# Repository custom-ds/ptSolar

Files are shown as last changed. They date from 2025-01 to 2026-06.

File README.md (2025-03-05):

# ptSolar
The ptSolar is the newest version of Project: Traveler's series of APRS trackers. The ptSolar has been designed and optimized for low-power operation, especially when using a solar panel.

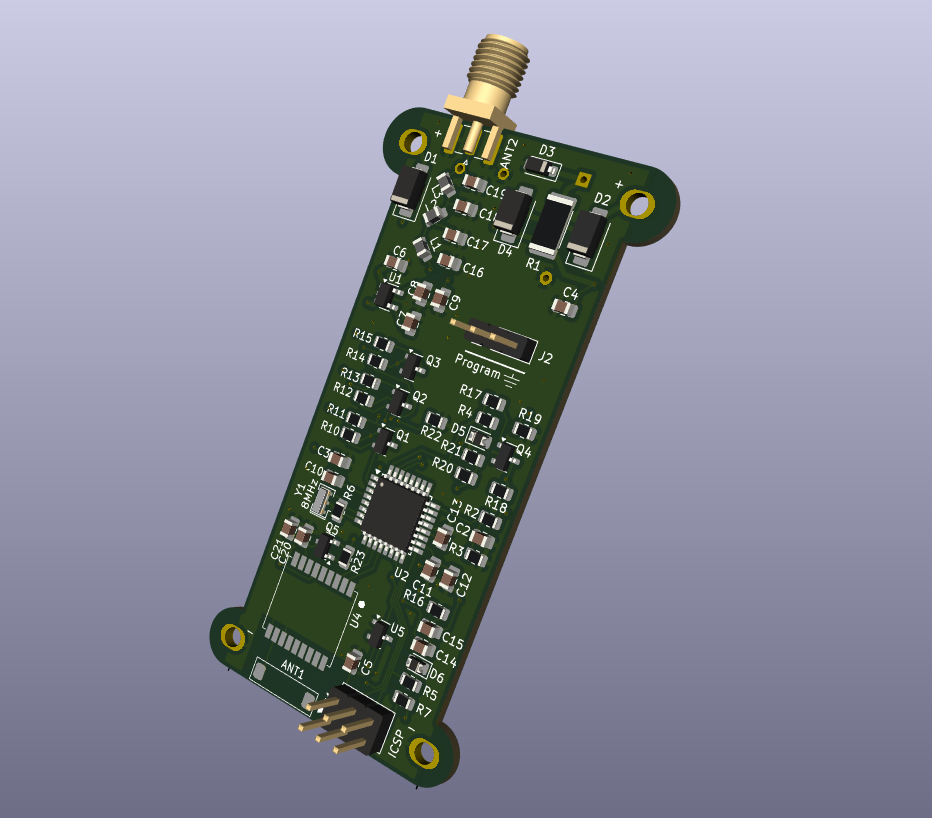
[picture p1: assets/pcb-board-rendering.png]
3D rendering of the ptSolar circuit board.


Under the hood, the ptSolar runs on the same __Microchip ATMega328p__ microcontroller that the other trackers have been using for years, although this board runs at a lower 3.3 volt level, and a slower 8MHz clock speed.

A 2m VHF transmitter is provided by the __SA818S-V__ transmitter-on-a-chip system, which means it's frequency agile and can be used throughout the world.

The GPS receiver is utilizes the __ATGM336H__ GPS engine which has a light-weight footprint while being a cost-effective solution. The ATGM336H is capable of position reports in excess of 60,000', making it a suitable solution for high altitude (latex) balloons traveling to over 100,000'.

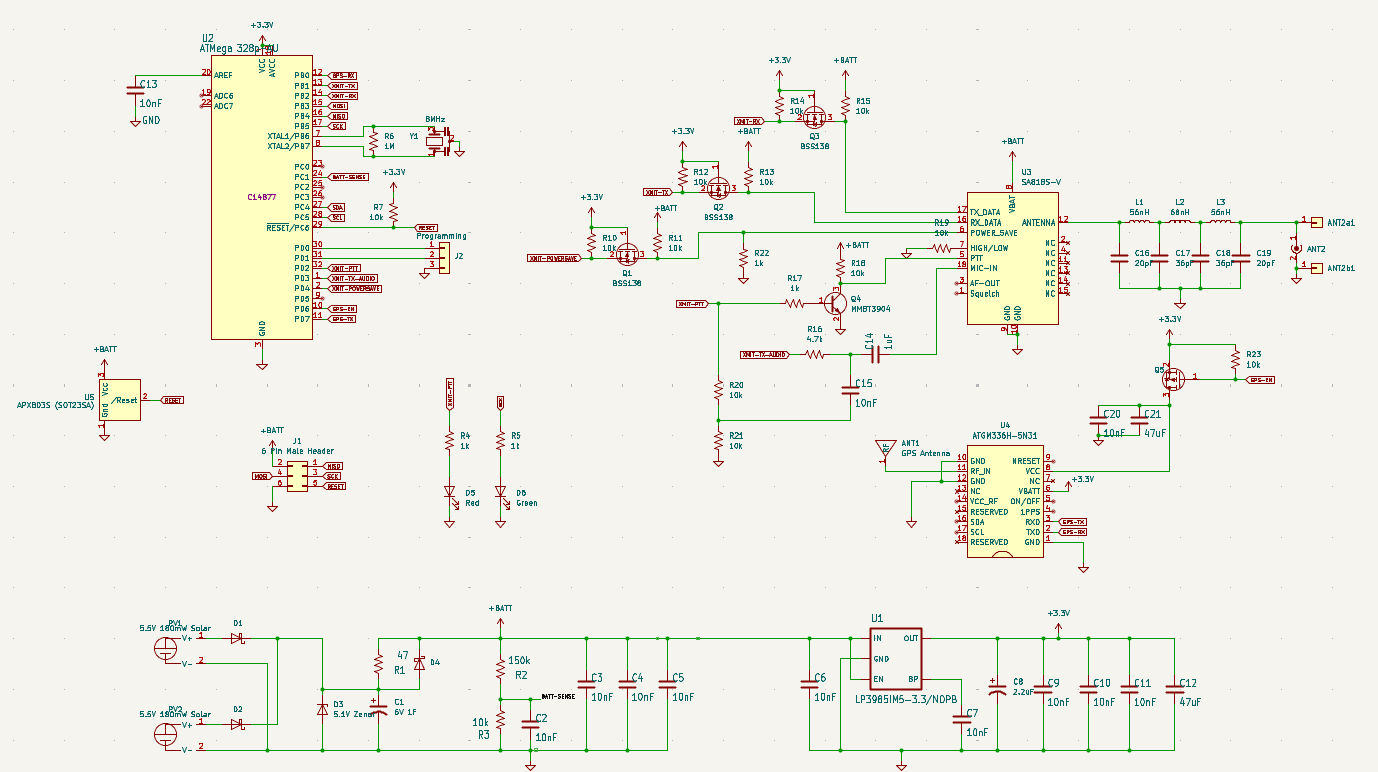
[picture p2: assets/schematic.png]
ptSolar schematic diagram.


## The Circuit Board
The circuit board is designed in Kicad and features a 4-layer design with castellated solder points for the attached solar panels.

The ptSolar is currently in the prototyping stages. Version 1.1.0 of the PCB was the initial design that was first built in early 2025, and includes the ATMega328p microcontroller, an ATGM336H GPS receiver, and the SA818S-V VHF transmitter. VHF signal filtering is provided by a 3-pole pi filter, reducing spurious harmonic output to well within Part 97 specifications.

## The Breakout Board
A Breakout board has been developed that can be temporarily or permanently paired to the top of the ptSolar tracker. The breakout includes a second ISCP programming port, a second serial data interface for configuring the tracker, a Sparkfun Qwiic connector for interfacing with other I2C sensors.

There is also a 2.1mm barrel jack for accepting power from a battery pack, along with the required 5V regulator when operating at higher supplied voltages. 

The Breakout Board mates to the tracker with a female .1" header connecting into the 6-pin (ISCP) and 8-pin (Serial, I2C) plugs on the ptSolar.

## Preparing the IDE for the Firmware
In the Arduino IDE and go to File &rarr; Preferences.  In the Additional Boards Manager URLs field, add the URL to the Project: Traveler website .json file:

```
https://www.projecttraveler.org/downloads/package_projecttraveler_index.json
```

Note that if there's already something in that field, you can click the small icon to the right of the text field where you are allowed to enter multiple entries on multiple lines.

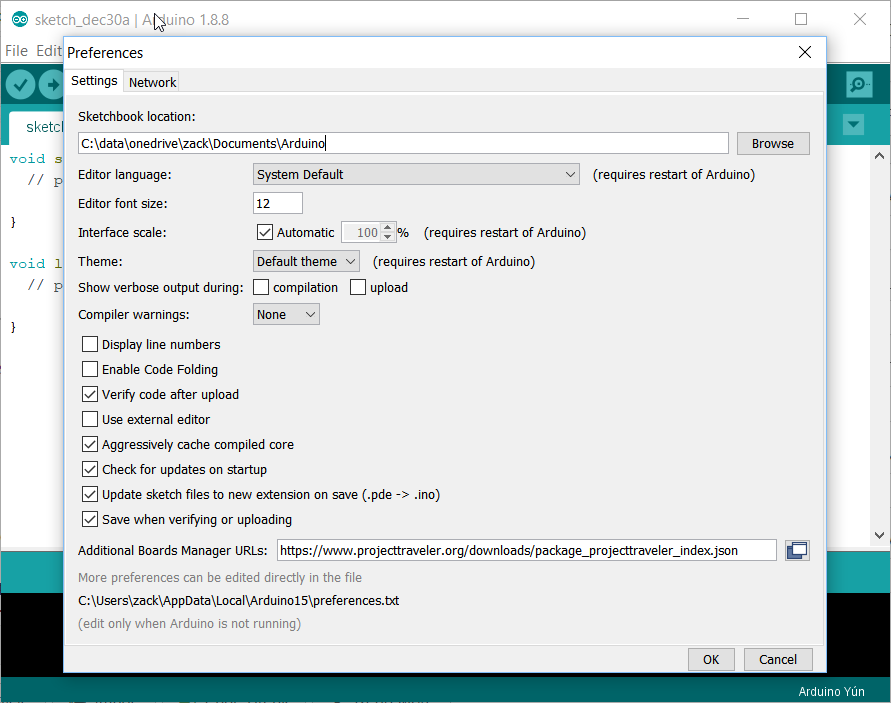
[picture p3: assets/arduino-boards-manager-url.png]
Setting the custom download URL for the Boards Manager.


Click OK to close the preferences dialog.  Then go to Tools &rarr; Boards &rarr; Boards Manager.

When the Boards Manager opens, select "Contributed" from the Type drop-down.  In the resulting list, you should find the Project Traveler Boards by Project Traveler option.  Click the Install button in the lower-right corner.

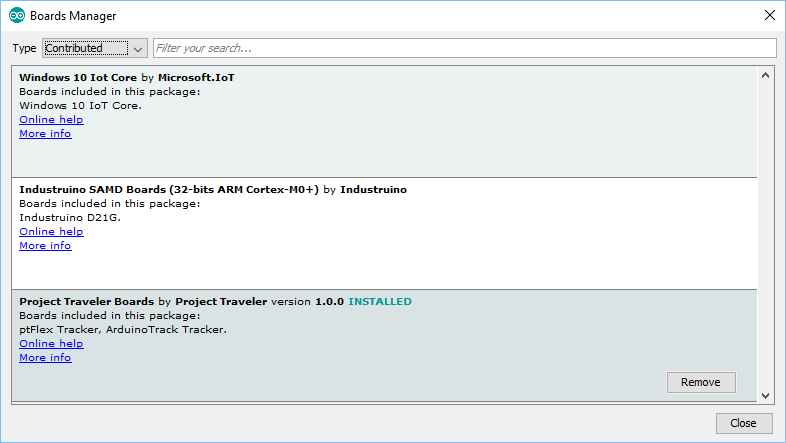
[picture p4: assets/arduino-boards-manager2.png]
Using the Boards Manager in Arduino IDE.


Close out of the Boards Manager dialog, and the back under Tools &rarr; Board, you should see "ptSolar Tracker (Arduino as ISP)" near the bottom of the list. 

## Setting the Controller Flags
If this is a brand new ptSolar board that has never been programmed before, there are several commands that must be run from a DOS command prompt. If the ptSolar was purchased as an assembled and tested kit, you can skip these steps.

The fuses are to be set as follows:
* Low: 0xFF
* High: 0xD6
* Extended: 0xFD

To program the fuses using the AVRDude tool (which is included in the Arduino IDE, and works with the Arduino As ISP programmer), open a command prompt on the PC.

```
C:\> cd \Program Files (x86)\Arduino\hardware\tools\avr\bin
C:\...> avrdude.exe -p m328p -b 19200 -c avrisp -C ..\etc\avrdude.conf -P comX* -U lfuse:w:0xDF:m -U hfuse:w:0xD6:m -U efuse:w:0xFD:m
```
Depending on your installation of the Arduino IDE, your avrdude may also be found in:

```
C:\Users\{Username}\AppData\Local\Arduino15\packages\arduino\tools\avrdude\6.3.0-arduino17\bin
```

This will write the fuses to the new processor.  To verify that the fuses have been written, run these commands:

```
avrdude.exe -p m328p -b 19200 -c avrisp -C ..\etc\avrdude.conf -P comX* -U lfuse:w:0xFF:m -U hfuse:w:0xD6:m -U efuse:w:0xFD:m 
```

\* Replace "comX" with whatever Com port your ArduinoISP is enumerating on.

### Verifying the Fuses
```
C:\...> avrdude.exe -p m328p -b 19200 -c avrisp -C ..\etc\avrdude.conf -P comX* -U lfuse:r:lowfuse:h -U hfuse:r:highfuse:h -U efuse:r:exfuse:h
C:\...> type lowfuse
C:\...> type highfuse
C:\...> type exfuse
```

\* Replace "comX" with whatever Com port your ArduinoISP is enumerating on.

## Loading the Firmware
To program the ptSolar, open the firmware Sketch in this GitHub Repository in the Arduino IDE. 

Go to the Tools &rarr; Board menu, select the "ptSolar Tracker (Arduino as ISP)" from the list of targets.  

The ptSolar boards are automatically configured to use the Arduino as ISP programmer to load the firmware onto the tracker boards, so no further configuration is necessary. Click the Upload button which will cause the Sketch to compile and will program to the ATmega328 processor similarly to how a normal Arduino board is programmed.

Sometimes it is necessary to apply external power to the ptSolar Tracker, depending on how much current the Programmer board is capable of sourcing.

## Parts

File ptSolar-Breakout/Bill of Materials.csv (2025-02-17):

Reference | Value | Datasheet | Footprint | Qty | DNP | Digikey
C1 | Piezo Buzzer | ~ | Capacitor_THT:CP_Radial_D12.5mm_P7.50mm | 1 |  | 102-1155-ND
C2,C4,C5,C6 | 10nF | ~ | Capacitor_SMD:C_0805_2012Metric | 4 |  | 399-1158-1-ND
C3 | 2.2uF | ~ | Capacitor_SMD:C_0805_2012Metric | 1 |  | 445-1420-1-ND
D1 | 1N4007FL |  | Diode_SMD:D_SOD-123 | 1 |  | 1655-1N4007FLCT-ND
J1 | 6 Pin Female Socket | ~ | Connector_PinHeader_2.54mm:PinHeader_2x03_P2.54mm_Vertical | 1 |  | 952-1781-ND
J2 | Qwiic | ~ | Connector_JST:JST_SH_SM04B-SRSS-TB_1x04-1MP_P1.00mm_Horizontal | 1 |  | 455-1804-1-ND
J3 | 6 Pin Male Header | ~ | Connector_PinHeader_2.54mm:PinHeader_2x03_P2.54mm_Vertical | 1 |  | 732-5394-ND
J4 | 8 Pin Female Socket | ~ | Connector_PinHeader_2.54mm:PinHeader_2x04_P2.54mm_Vertical | 1 |  | 952-1790-ND
J5 | 3 Pin Male Header | ~ | Connector_PinHeader_2.54mm:PinHeader_1x03_P2.54mm_Vertical | 1 |  | 732-5316-ND
J6 | Barrel_Jack_Switch | ~ | Connector_BarrelJack:BarrelJack_CLIFF_FC681465S_SMT_Horizontal | 1 |  | CP-002AHPJCT-ND
Q1 | MMBT3904 | https://www.onsemi.com/pdf/datasheet/pzt3904-d.pdf | Package_TO_SOT_SMD:SOT-23 | 1 |  | MMBT3904TPMSCT-ND
R1 | 1k | ~ | Resistor_SMD:R_0805_2012Metric | 1 |  | 311-1.0KARCT-ND
SW2 | Reset Switch | ~ | Button_Switch_SMD:SW_SPST_B3S-1000 | 1 |  | CKN9104CT-ND
U1 | LM1086-5.0 |  | Package_TO_SOT_SMD:TO-263-3_TabPin2 | 1 |  | LM1086ISX-5.0/NOPBCT-ND

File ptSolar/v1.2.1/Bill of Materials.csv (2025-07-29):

Reference | Value | Datasheet | Footprint | Qty | DNP | Digikey | LCSC
ANT1 | GPS Antenna |  | Custom DS:Pulse ANT8010LL05R1575A Antenna | 1 |  | 553-ANT8010LL05R1575ACT-ND | C3284202
ANT2 | SMA Edge Mount (Optional) | ~ | Connector_Coaxial:SMA_Samtec_SMA-J-P-H-ST-EM1_EdgeMount | 1 |  | CON-SMA-EDGE-S-ND
ANT2a1,ANT2b1 | VHF Test Point | ~ | Custom DS:Small Test Point Pin | 2
C1 | 6V 1F | ~ | Custom DS:CDS CSP Super Cap 8mm dia | 1 |  | 4688-CSP-6R0L105R-TW-ND
C2,C3,C4,C5,C6,C7,C9,C10,C11,C13,C15,C20 | 10nF | ~ | Capacitor_SMD:C_0805_2012Metric | 12 |  | 399-1158-1-ND | C83170
C8 | 2.2uF | ~ | Capacitor_SMD:C_0805_2012Metric | 1 |  | 445-1420-1-ND | C107128
C12,C21 | 47uF | ~ | Capacitor_SMD:C_0805_2012Metric | 2 |  | 399-C0805C476M9PACTUCT-ND | C16780
C14 | 1uF | ~ | Capacitor_SMD:C_0805_2012Metric | 1 |  | 311-1886-1-ND | C28323
C16,C19 | 20pF | ~ | Capacitor_SMD:C_0805_2012Metric | 2 |  | 712-1381-1-ND | C105173
C17,C18 | 36pF | ~ | Capacitor_SMD:C_0805_2012Metric | 2 |  | 478-10473-1-ND | C541518
D1,D2,D4 | CDBA340L-G Schottky | ~ | Diode_SMD:D_SMA | 3 |  | 641-1258-1-ND | C22364900
D3 | 5.1V Zenor | ~ | Diode_SMD:D_SOD-123 | 1 |  | MMSZ5231B-FDICT-ND | C85181
D5 | Red | ~ | Diode_SMD:D_0805_2012Metric | 1 |  | LTST-C171KRKT | C2295
D6 | Green | ~ | Diode_SMD:D_0805_2012Metric | 1 |  | LTST-C171GKT | C2297
J1 | 6 Pin Male Header | ~ | Connector_PinHeader_2.54mm:PinHeader_2x03_P2.54mm_Vertical | 1 |  | 732-5394-ND
J2 | Programming | ~ | Connector_PinHeader_2.54mm:PinHeader_1x03_P2.54mm_Vertical | 1 |  | 732-5316-ND
L1,L3 | 56nH | ~ | Inductor_SMD:L_0805_2012Metric | 2 |  | 535-11570-1-ND | C98996
L2 | 68nH | ~ | Inductor_SMD:L_0805_2012Metric | 1 |  | 535-11572-1-ND | C75652
PV1,PV2 | 5.5V 180mW Solar | https://www.powerfilmsolar.com/hubfs/documents/spec%20sheets/electronic%20component%20solar%20panels/electronic%20component%20solar%20panels%20spec%20sheet_cl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 | Custom DS:PowerFilm MPT3.6-75 | 2 |  | 1996-1020-ND
Q1,Q2,Q3 | BSS138 | https://www.onsemi.com/pub/Collateral/BSS138-D.PDF | Package_TO_SOT_SMD:SOT-23 | 3 |  | BSS138TR-ND | C40912
Q4 | MMBT3904 | https://www.onsemi.com/pdf/datasheet/pzt3904-d.pdf | Package_TO_SOT_SMD:SOT-23 | 1 |  | MMBT3904TPMSCT-ND | C81464
Q5 | DMP2004K-7 |  | Package_TO_SOT_SMD:SOT-23 | 1 |  | DMP2004KDICT-ND | C332297
R1 | 47 | ~ | Resistor_SMD:R_2512_6332Metric | 1 |  | YAG3404CT-ND | C513678
R2 | 150k | ~ | Resistor_SMD:R_0805_2012Metric | 1 |  | 311-150KCRCT-ND | C114558
R3,R7,R10,R11,R12,R13,R14,R15,R18,R19,R20,R21,R23 | 10k | ~ | Resistor_SMD:R_0805_2012Metric | 13 |  | 13-RT0805FRD0710KLCT-ND | C100047
R4,R5,R17,R22 | 1k | ~ | Resistor_SMD:R_0805_2012Metric | 4 |  | 311-1.0KARCT-ND | C95781
R6 | 1M | ~ | Resistor_SMD:R_0805_2012Metric | 1 |  | 311-1.0MARCT-ND | C107700
R16 | 4.7k | ~ | Resistor_SMD:R_0805_2012Metric | 1 |  | 311-4.7KARCT-ND | C60816
U1 | LP3985IM5-3.3/NOPB | https://www.ti.com/lit/ds/symlink/lp3985.pdf?HQS=dis-dk-null-digikeymode-dsf-pf-null-wwe&ts=1737860010554 | Package_TO_SOT_SMD:SOT-23-5 | 1 |  | LP3985IM5-3.3/NOPBCT-ND | C108877
U2 | ATMega 328p-AU | https://ww1.microchip.com/downloads/en/DeviceDoc/Atmel-7810-Automotive-Microcontrollers-ATmega328P_Datasheet.pdf | Package_QFP:TQFP-32_7x7mm_P0.8mm | 1 |  | ATMEGA328P-AU-ND | C14877
U3 | SA818S-V |  | Custom DS:DRA818 SA818 | 1 |  | ALIEXPRESS
U4 | ATGM336H-5N31 | https://www.tinytronics.nl/product_files/002176_ATGM336H.pdf | Custom DS:ATGM336H-5N31 | 1 |  | ALIEXPRESS | C90770
U5 | APX803S (SOT23SA) |  | Package_TO_SOT_SMD:SOT-23 | 1 |  | APX803S-31SA-7DICT-ND | C129757
Y1 | 8MHz | ~ | Crystal:Resonator_SMD_Murata_CSTxExxV-3Pin_3.0x1.1mm | 1 |  | 490-CSTNE8M00G520000R0CT-ND | C907975

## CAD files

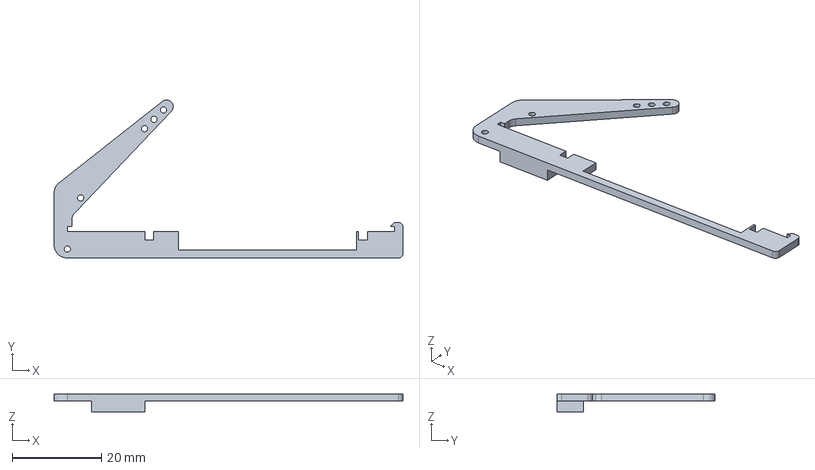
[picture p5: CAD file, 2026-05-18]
3d-prints/Angled Carrier.FCStd
78.4 x 35.5 x 4.00 mm

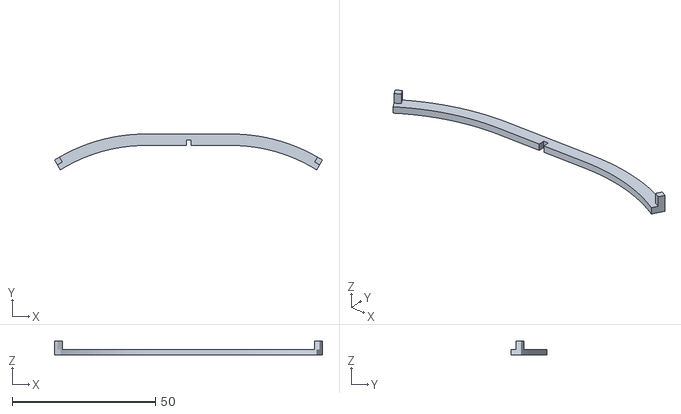
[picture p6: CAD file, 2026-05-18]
3d-prints/Rib.stl
93.5 x 12.5 x 5.00

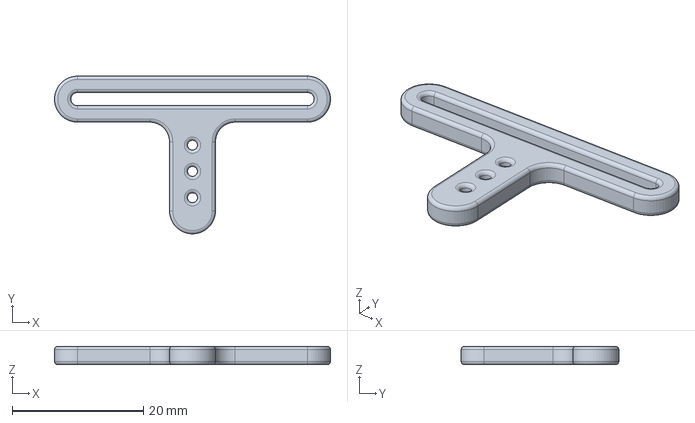
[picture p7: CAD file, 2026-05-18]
3d-prints/Balloon Neck Hanger.FCStd
42.0 x 24.0 x 2.80 mm

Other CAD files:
3d-prints/Spar.stl
3d-prints/Balloon Neck Hanger.stl

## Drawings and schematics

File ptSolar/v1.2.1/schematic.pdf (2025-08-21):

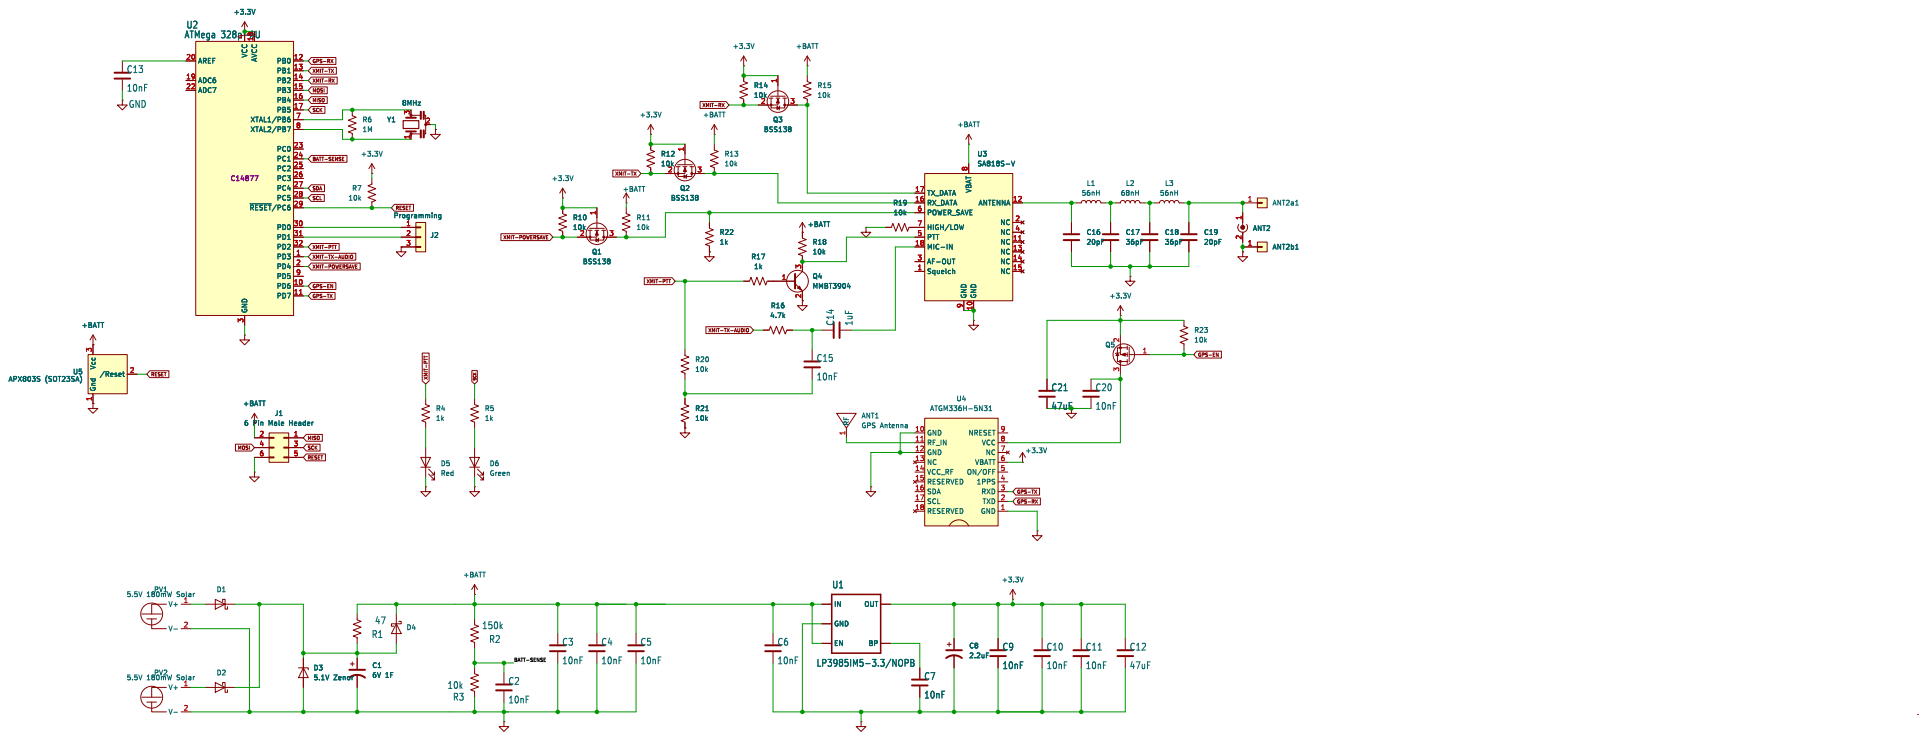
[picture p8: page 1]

SCK GPS-RX
XMIT-TX
XMIT-RX
XMIT-POWERSAVE MOSI MISO

8 GND 10 ANTENNA 12 NC 2 NC 4 NC 11 NC 13 NC 14 NC 15 U3SA818S-V

8 GND 10 ANTENNA 12 NC 2 NC 4 NC 11 NC 13 NC 14 NC 15 R19

3 2 Q5 +BATT D1 V+ 1 V- 2 PV1 5.5V 180mW Solar +3.3V GND 10 RF_IN 11 GND 12 NC 13 VCC_RF 14 RESERVED 15 SDA 16 SCL 17 RESERVED 18 NRESET 9 VCC 8 NC 7 VBATT 6 ON/OFF 5

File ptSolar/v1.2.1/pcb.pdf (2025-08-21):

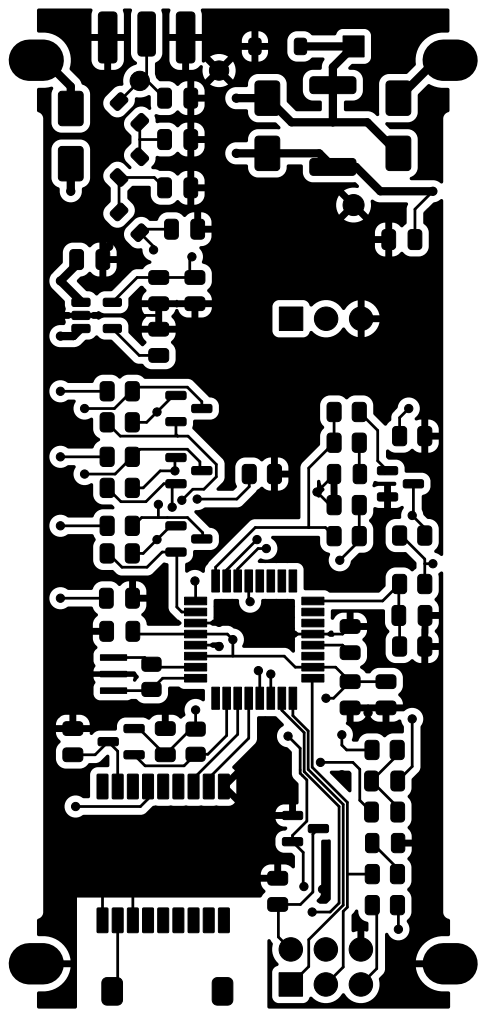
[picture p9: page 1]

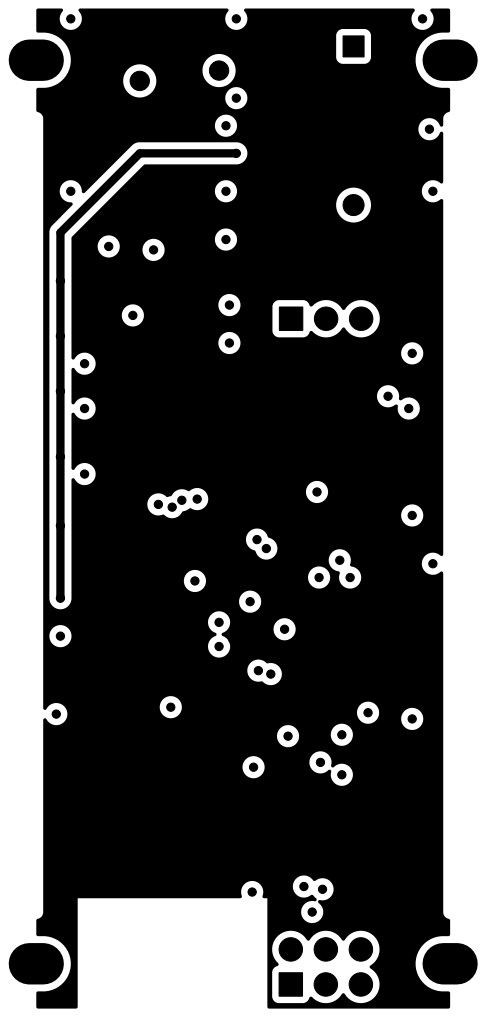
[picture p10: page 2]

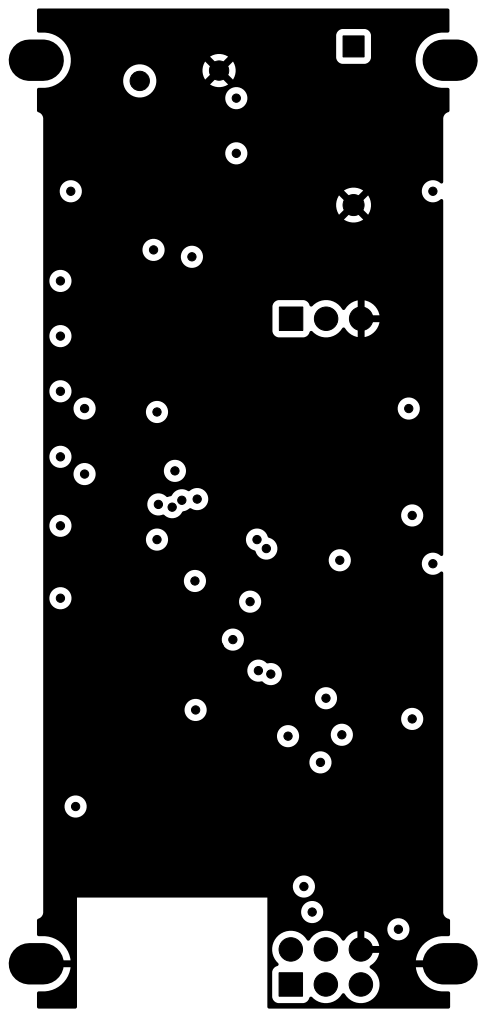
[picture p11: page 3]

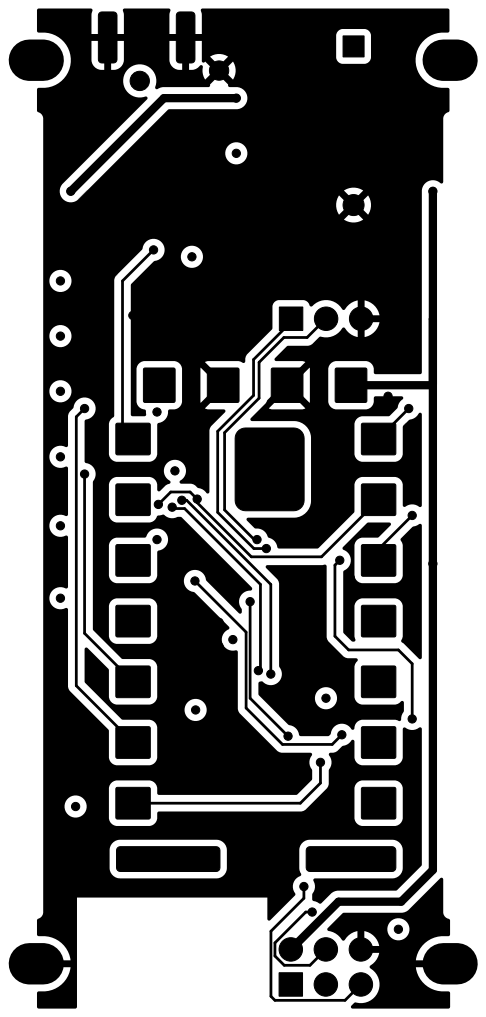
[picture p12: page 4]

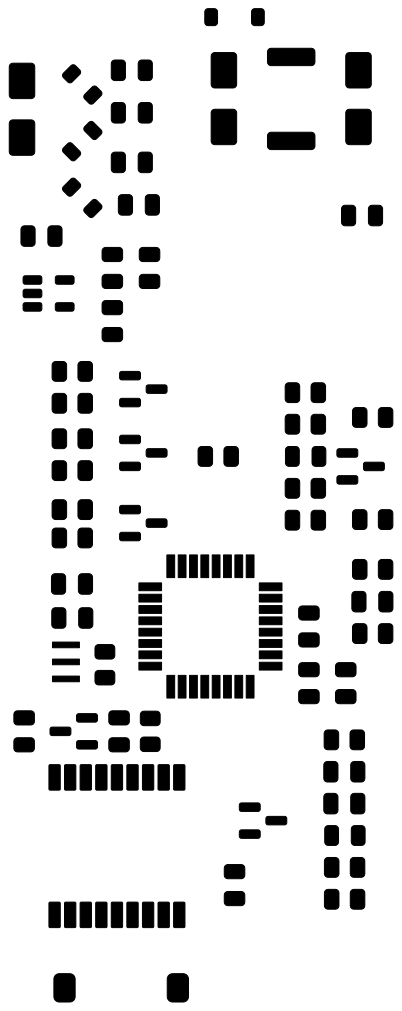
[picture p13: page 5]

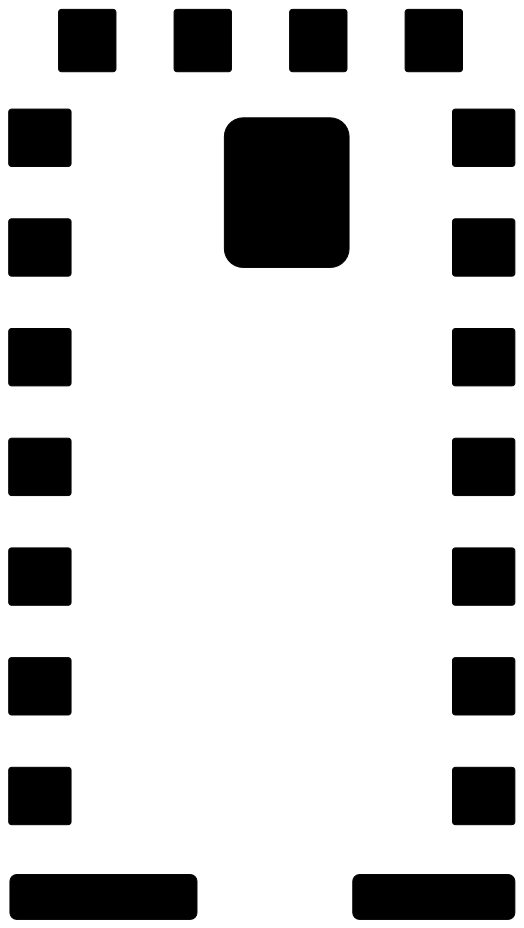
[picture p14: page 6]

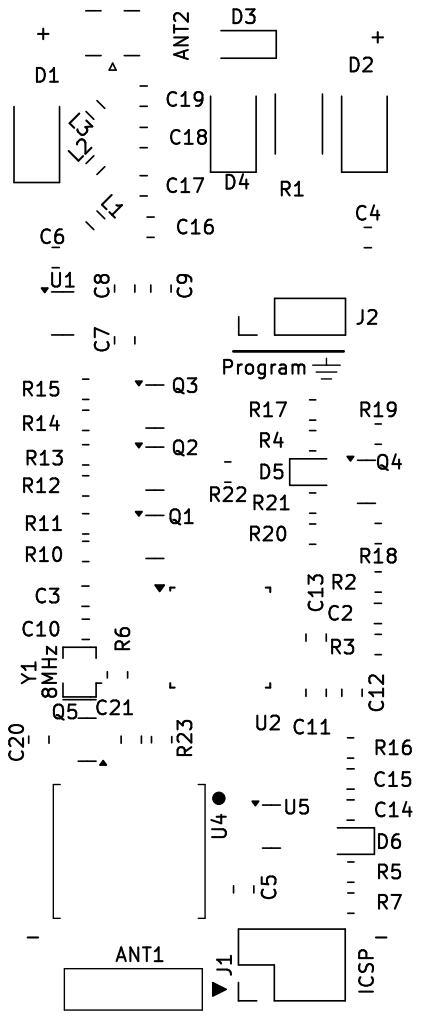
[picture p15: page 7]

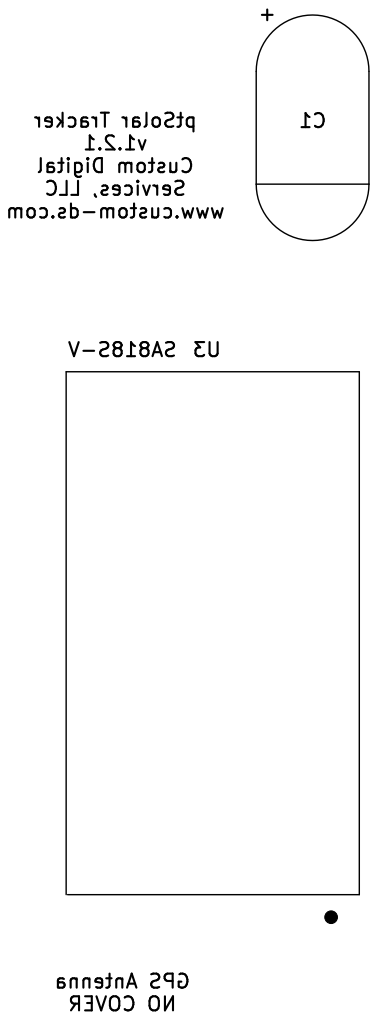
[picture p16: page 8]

LLC Services, www.custom-ds.com

Antenna GPS COVER NO

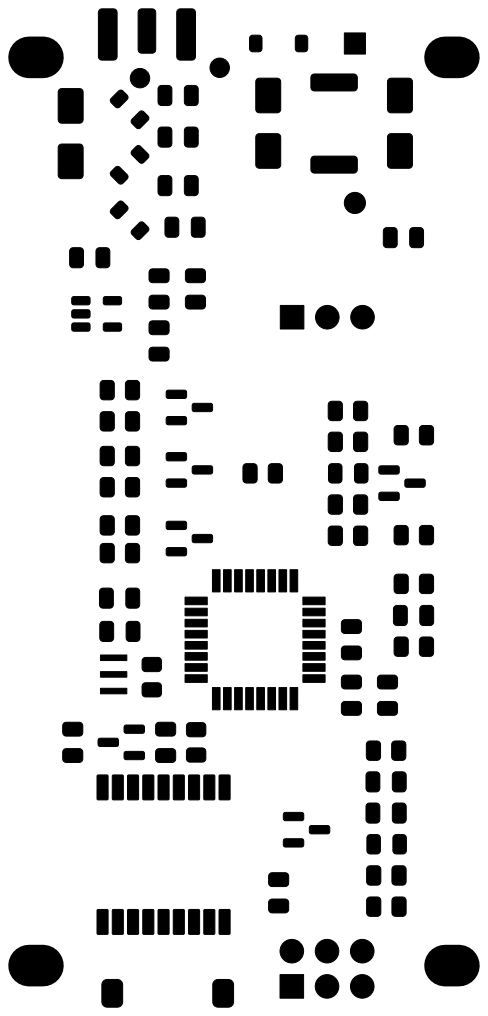
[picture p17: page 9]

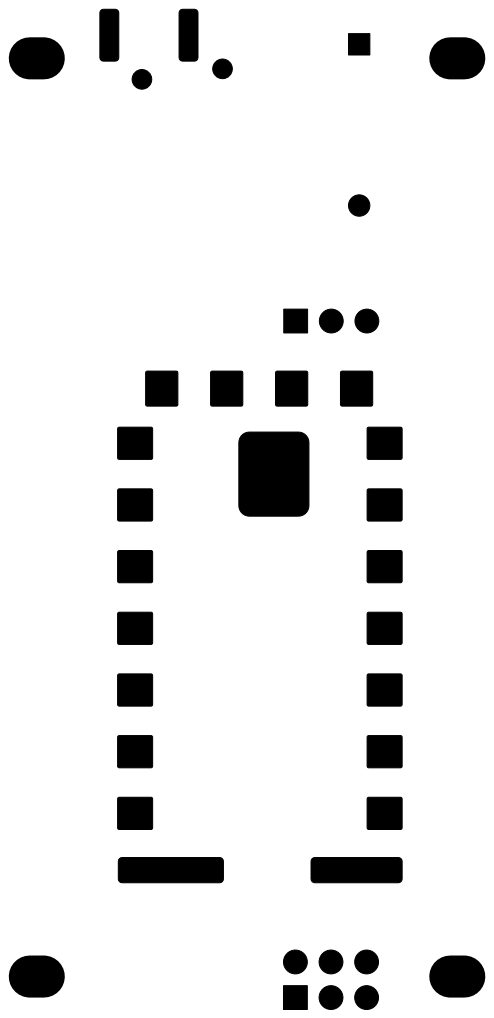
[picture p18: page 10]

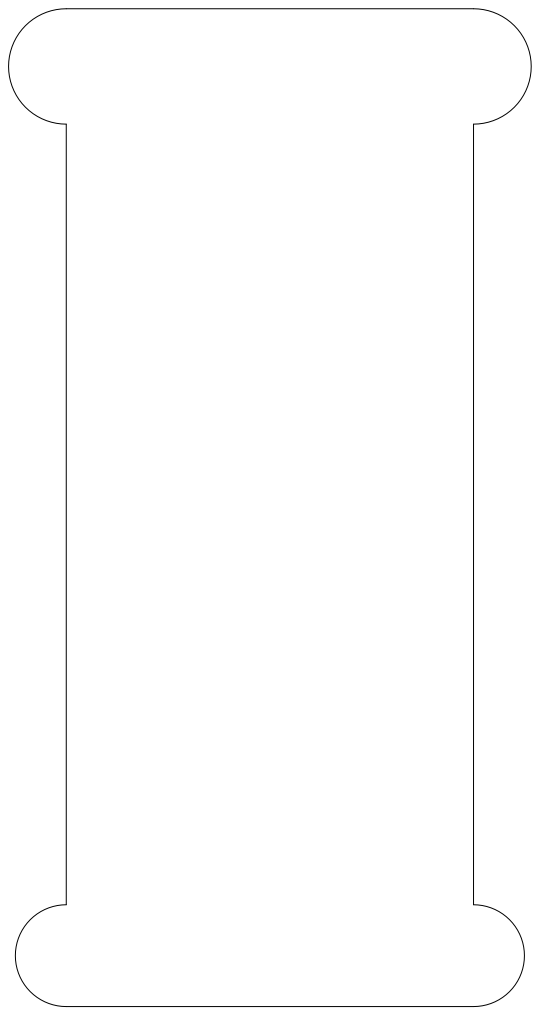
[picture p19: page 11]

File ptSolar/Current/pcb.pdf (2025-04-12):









LLC Services, www.custom-ds.com

Antenna GPS COVER NO









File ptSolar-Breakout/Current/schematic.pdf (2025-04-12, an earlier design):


6 Pin Male Header 1

7 SDO 5 SCK 4 SDI 3 CSB 2 U2 BME280 C1

7 SDO 5 SCK 4 SDI 3 CSB 2 C2

6 6 | 3 3
8 8 | | 2 2

Id: 1/1 Title: File: ptSolar-Breakout.kicad_sch Sheet: /

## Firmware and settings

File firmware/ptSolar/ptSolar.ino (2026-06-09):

/*
Project: Traveler ptSolar Firmware
Copyright 2011-2026 - Zack Clobes (W0ZC), Custom Digital Services, LLC


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
You should have received a copy of the GNU General Public License along with this program.  If not, see <http://www.gnu.org/licenses/>.


Before programming for the first time, the ATmega fuses must be set.
 Low:      0xDF
 High:     0xD6
 Extended: 0xFD

*/


#define FIRMWARE_VERSION "1.6.2"
#define CONFIG_PROMPT "\n\n# "
#include "BoardDef.h"   //defines if this is a ptFlex or ptSolar PCB board


#define __PROG_TYPES_COMPAT__
#include <avr/pgmspace.h>
#include <avr/wdt.h>

#include "ptConfig.h"
#include "Modem.h"
#include "GPS.h"
#include "ptTracker.h"

#include "SparkFunBME280.h"
#include <Wire.h>

//PD0 is Serial Port RX
//PD1 is Serial Port TX
#define PIN_PTT_OUT 2     //PD2
#define PIN_AUDIO_OUT 3   //PD3   - APRS Packet Audio
#define PIN_DRA_EN 4      //PD4
#define PIN_AUDIO 5       //PD5   - Audio Annunciation
#define PIN_GPS_EN 6      //PD6
#define PIN_GPS_TX 7      //PD7

#define PIN_GPS_RX 8      //PB0
#define PIN_DRA_TX 9      //PB1
#define PIN_DRA_RX 10     //PB2
//PB3 is MOSI
//PB4 is MISO
#define PIN_LED 13        //PB5

//Analog Pins
#define PIN_AUDIO_IN A0   //PC0
#define PIN_ANALOG_BATTERY A1   //PC1
//PC2 is not used
//PC3 is not used
//PC4 is SDA
//PC5 is SCL
//PC6 is reset and not available


#define DELAY_MS_BETWEEN_XMITS 1250   //How many MS to delay between subsequent packets (as in between GPGGA and GPRMC strings
#define INVALID_GPS_DELAY 50000    //Max additional ms to wait for a GPS fix before transmitting anyway
#define METERS_TO_FEET 3.2808399

//Debugging options
#define XMIT_MILLIS true
#define WATCHDOG


ptConfig Config;                                                                        //Configuration object
ptTracker Tracker(PIN_LED, PIN_AUDIO, PIN_ANALOG_BATTERY, Config.getAnnounceMode());    //Object that manages the board-specific functions
GPS GPSParser(PIN_GPS_RX, PIN_GPS_TX, PIN_GPS_EN);                                      //Object that parses the GPS strings
Modem Aprs(PIN_DRA_EN, PIN_PTT_OUT, PIN_AUDIO_OUT, PIN_DRA_TX, PIN_DRA_RX);;            //Object that assembles the packets for the TNC and transmits them

BME280 Pressure;      //BMP280 pressure/temp sensor

bool bHasBurst;
float fMaxAlt;
float fMaxSpeed;


/**
 * @brief  The function that runs first before the main loop() function is called indefinitely.
 * @note   This function is called once at startup and is used to initialize the board and set up the hardware.
 */
void setup() {
  Serial.begin(19200);

  wdt_disable();    //disable the watchdog timer by default
  #ifdef WATCHDOG
    wdt_enable(WDTO_8S);    //Enable the Watchdog if configured
  #endif

  wdt_reset();    //reset the watchdog timer (even if we're not using it)
  showVersion();    //show the version of the firmware that we're running


  //Init some variables
  fMaxAlt = 0;
  fMaxSpeed = 0;
  bHasBurst = false;

  Tracker.annunciate('k');

  //Additional configurations for the APRS Modem
  Aprs.setDebugLevel(1);
  Aprs.setTxDelay(Config.getRadioTxDelay());
  Aprs.setCourtesyTone(Config.getRadioCourtesyTone());

  //init the I2C devices
  if (Config.getI2cBME280() == 1) {
    //we're supposed to initialize the BME280
    Serial.println(F("Init BME280"));
    Pressure.setI2CAddress(0x76);

    //Begin communication over I2C
    if (Pressure.beginI2C() == false) {
      Serial.println(F(" Could NOT init!"));
    }
  } else {
    Serial.println(F("No I2C devices to init"));
  }
  
  GPSParser.setDebugNEMA(true);    ///TODO: Need to pull this from Configuration
  GPSParser.setDebugLevel(1);    //Get full verbose output from the GPS
}


/**
 * @brief  Main loop for the program.  This is where the main logic of the program is executed.
 * @note   This function will run continuously until the board is powered off or reset.
 */
void loop() {

  float fCurrentAlt, fSpeed;
  unsigned long battMillivolts;
  bool bXmit;             //Flag to indicate whether or not we should transmit this time around
  bool bXmitPermitted;    //Flag that can be set to false to prevent transmission, such as when we're in a country that doesn't allow APRS
  bool bISSPath;          //Flag to see if we should set the APRS Path to transmit up to the ISS
  int iSeconds;
  unsigned long msDelay;    //calculate the number of milliseconds to delay
  byte byTemp;
  char szFreq[9];    //The frequency to transmit on


  wdt_reset();
  
  //Check to see if we have a command from the serial port to indicate that we need to enter config mode
  if (Serial.available()) {
    byTemp = Serial.read();
    if (byTemp == '!') {
      doConfigMode();
    }
  }

  //Reboot the system hourly if configured to do so
  if (Config.getRebootHourly()) {
    //Reboot if we've been running for 60 minutes
    if (millis() > 3600000) {
      //we've been running for 60 minutes - reboot the system
      Serial.println(F("60min Reboot"));
      delay(1000);
      Tracker.reboot();
    }
  }

  battMillivolts = (unsigned long)(Tracker.readBatteryVoltage(true) * 1000);  //read the battery voltage and spit it out to the serial port

  //check to see if we have sufficient battery to run the GPS
  if (battMillivolts >= Config.getVoltThreshGPS()) {
    GPSParser.enableGPS(true);    //enable the GPS module if it's not already. If it wasn't enabled, this will also initialize it.

    GPSParser.collectGPSStrings();
    fCurrentAlt = GPSParser.Altitude();        //get the current altitude
    if (fCurrentAlt > fMaxAlt) {
      fMaxAlt = fCurrentAlt;
    } else {
      if (fMaxAlt > 10000 && (fCurrentAlt < (fMaxAlt - 250))) {
        //Check for burst.  The Burst must be at least 10,000m MSL.
        // To sense a burst, the controller must have fallen at least 250m from the max altitude
  
        bHasBurst = true;
      }
    }
  } else {
    //See if the Battery has dropped 100mV below the threshold.  If so, disable the GPS until the battery comes back up
    if (battMillivolts < (Config.getVoltThreshGPS() - 100)) {
      //we don't have enough battery to run the GPS - disable it
      Serial.println(F("Disabling GPS"));
      GPSParser.disableGPS();
    }
    Serial.println(F("Low Batt, no GPS"));
    delay(750);   //wait for about the amount of time that we'd normally spend grabbing a GPS reading
  }

  bXmit = false;    //assume that we won't transmit this time around

  //Figure out how long to delay before the next packet
  switch (Config.getBeaconType()) {
  case 0:
    //This is no logic to beacon intervals - just plan old time delays
    msDelay = (unsigned long)Config.getBeaconSimpleDelay() * 1000;    //cast this to unsigned long
    if (!GPSParser.FixValid()) {
      Tracker.debugMessage(ptTracker::DEBUG_GPS_INVALID_LOCK);
      msDelay += INVALID_GPS_DELAY;
    }

    if ((millis() - Aprs.getLastTransmitMillis()) > msDelay) {
      //we've waited long enough - transmit
      bXmit = true;
    }

    break;
  case 1:
    //This is for Speed-based beaconing

    if (GPSParser.FixValid()) {
      fSpeed = GPSParser.Knots();        //get the current speed
      if (fSpeed > fMaxSpeed) fMaxSpeed = fSpeed;

      if (fMaxSpeed < Config.getBeaconSpeedThreshLow()) {
        //we're in the slow range
        msDelay = (unsigned long)Config.getBeaconSpeedDelayLow() * 1000;    //cast this to unsigned long

        if ((millis() - Aprs.getLastTransmitMillis()) > msDelay) {
          //we've waited long enough for this speed - transmit
          bXmit = true;
        }
      }

      if (fSpeed >= Config.getBeaconSpeedThreshLow() && fSpeed < Config.getBeaconSpeedThreshHigh()) {
        //we're in the medium range
        msDelay = (unsigned long)Config.getBeaconSpeedDelayMid() * 1000;    //cast this to unsigned long

        if ((millis() - Aprs.getLastTransmitMillis()) > msDelay) {
          //we've waited long enough for this speed - transmit
          bXmit = true;
        }
      }

      if (fSpeed >= Config.getBeaconSpeedThreshHigh()) {
        //we're in the fast range
        msDelay = (unsigned long)Config.getBeaconSpeedDelayHigh() * 1000;    //cast this to unsigned long

        if ((millis() - Aprs.getLastTransmitMillis()) > msDelay) {
          //we've waited long enough for this speed - transmit
          bXmit = true;
        }
      }
    } else {
      //No GPS fix - use the high speed delay + GPS fix timeout before transmitting anyway
      Tracker.debugMessage(ptTracker::DEBUG_GPS_INVALID_LOCK);

      msDelay = (unsigned long)Config.getBeaconSpeedDelayHigh() * 1000;
      if ((millis() - Aprs.getLastTransmitMillis()) > (msDelay + INVALID_GPS_DELAY)) {
        Tracker.debugMessage(ptTracker::DEBUG_DELAY_XMIT_CONTINUE);
        bXmit = true;
      }
    }

    break;
  case 2:
    //This is for Altitude-based beaconing

    if (GPSParser.FixValid()) {
      if (fCurrentAlt < Config.getBeaconAltitudeThreshLow()) {
        //we're in the low phase of the flight - we'll typically send packets more frequently close to the ground
        msDelay = (unsigned long)Config.getBeaconAltitudeDelayLow() * 1000;    //cast this to unsigned long

        if ((millis() - Aprs.getLastTransmitMillis()) > msDelay) {
          //we've waited long enough for this speed - transmit
          bXmit = true;
        }
      }
      if (fCurrentAlt >= Config.getBeaconAltitudeThreshLow() && fCurrentAlt < Config.getBeaconAltitudeThreshHigh()) {
        //we're in the mid-phase of the flight.  We'll transmit regularly in here
        msDelay = (unsigned long)Config.getBeaconAltitudeDelayMid() * 1000;    //cast this to unsigned long

        if ((millis() - Aprs.getLastTransmitMillis()) > msDelay) {
          //we've waited long enough for this speed - transmit
          bXmit = true;
        }
      }
      if (fCurrentAlt >= Config.getBeaconAltitudeThreshHigh()) {
        //we're in the top-phase of the flight.  Transmit more frequenly to get better burst resolution?
        msDelay = (unsigned long)Config.getBeaconAltitudeDelayHigh() * 1000;    //cast this to unsigned long

        if ((millis() - Aprs.getLastTransmitMillis()) > msDelay) {
          //we've waited long enough for this speed - transmit
          bXmit = true;
        }
      }
    } else {
      //No GPS fix - use the low altitude delay + GPS fix timeout before transmitting anyway
      Tracker.debugMessage(ptTracker::DEBUG_GPS_INVALID_LOCK);

      msDelay = (unsigned long)Config.getBeaconAltitudeDelayLow() * 1000;
      if ((millis() - Aprs.getLastTransmitMillis()) > (msDelay + INVALID_GPS_DELAY)) {
        Tracker.debugMessage(ptTracker::DEBUG_DELAY_XMIT_CONTINUE);
        bXmit = true;
      }
    }

    break;
  case 3:
    //Use Time Slotting to determine when to transmit
    iSeconds = GPSParser.getGPSSeconds();

    if (iSeconds == Config.getBeaconSlot1() || iSeconds == (Config.getBeaconSlot1() + 1) || iSeconds == Config.getBeaconSlot2() || iSeconds == (Config.getBeaconSlot2() + 1)) {
      if (Config.getDelayXmitUntilGPSFix()) {
        if (GPSParser.FixValid()) {
          bXmit = true;   //have a valid fix, and it's in our slot. Just transmit
        } else {
          //See if we've haven't transmitted within the INVALID_GPS_DELAY time window.  If we haven't, then transmit anyway
          if ((millis() - Aprs.getLastTransmitMillis()) > INVALID_GPS_DELAY) {
            Tracker.debugMessage(ptTracker::DEBUG_DELAY_XMIT_CONTINUE);
            bXmit = true;
          } else {
            Tracker.debugMessage(ptTracker::DEBUG_DELAY_XMIT);
          }
        }
      } else {
        bXmit = true;   //we don't care about the GPS fix, and it's in our slot. Just transmit
      }
    }

    break;
  case 4:
    //This is a voltage-checked time delay.  It will wait X seconds, but then also wait for the system (solar) voltage to be above a threshold before transmitting
    msDelay = (unsigned long)Config.getMinTimeBetweenXmits() * 1000;    //cast this to unsigned long
    
    if ((millis() - Aprs.getLastTransmitMillis()) > msDelay) {
      //we've waited long enough - see if we have the power to transmit
      if (battMillivolts > Config.getVoltThreshXmit()) {
        
        //We have power to transmit, see if we have a valid GPS fix
        if (GPSParser.FixValid()) {
          //we have a valid GPS fix - transmit
          bXmit = true;
        } else {
          //we don't have a valid GPS fix - Allow up to msDelay + 60s to wait for a fix

          if (Config.getDelayXmitUntilGPSFix()) {
            Tracker.debugMessage(ptTracker::DEBUG_GPS_INVALID_LOCK);
            if ((millis() - Aprs.getLastTransmitMillis()) > (msDelay + INVALID_GPS_DELAY)) {
              //we've waited long enough for a fix - transmit anyway
              Tracker.debugMessage(ptTracker::DEBUG_DELAY_XMIT_CONTINUE);
              bXmit = true;
            } else {
              Tracker.debugMessage(ptTracker::DEBUG_DELAY_XMIT);
            }
          } else {
            bXmit = true;    //we have a valid GPS fix - transmit
          }
        }
      } else {
        Serial.println("Low Batt - no xmit");
      }
    }

    break;    
  }

  
  if (bXmit) {
    bXmitPermitted = true;    //assume that we can transmit
    bISSPath = false;    //assume that we're not using the ISS path

    //Determine the transmit/receive frequency to use
    if (Config.getUseGlobalFreq()) {
      //Look up the current APRS frequency from the GPS Position
      bXmitPermitted = GPSParser.getAPRSFrequency(szFreq);
      Aprs.setTxFrequency(szFreq);    //set the frequency to transmit on
      Aprs.setRxFrequency(szFreq);    //set the frequency to receive on

      //if we're on 145.8250 MHz, then we should use the ISS path
      if (szFreq[2] == '5' && szFreq[4] == '8' && szFreq[5] == '2' && szFreq[6] == '5') {
        //we're on the ISS frequency - use the ISS path
        bISSPath = true;
      }
    } else {
      //we're supposed to use the local frequency - set it up
      Aprs.setTxFrequency(Config.getRadioFreqTx());    //set the frequency to transmit on
      Aprs.setRxFrequency(Config.getRadioFreqRx());    //set the frequency to receive on
    }

    //we're supposed to transmit now
    if (bXmitPermitted) {
      wdt_reset();  

      if (Config.getDisableGPSDuringXmit()) {
        //Disable the GPS to save power
        GPSParser.disableGPS();     //disable the GPS module before transmitting
      }

      sendPositionSingleLine(bISSPath);
    } else {
      Aprs.setLastTransmitMillis();   //reset the last transmit time so that we don't try to transmit again immediately.
      Serial.println(F("Xmit Prohibit"));
    }

    fMaxSpeed = 0;    //reset the max speed to check again this next cycle (Used for Speed-based smart beaconing)
    delay(DELAY_MS_BETWEEN_XMITS);    //delay about a second - if you don't you can run into multiple packets inside of a 2 second window

    if (!GPSParser.FixQuality() || GPSParser.NumSats() < 4) {
      //we are having GPS fix issues - issue an annunciation
      Tracker.annunciate('l');
    }
  } 
}


/**
 * @brief sendPositionSingleLine - This function sends the position of the tracker in a single line format. It includes information such as GPS time, latitude, longitude, course, speed, altitude, and other telemetry data.
 * @param bISSPath A boolean indicating whether or not to use the alternate path for communicating via the ISS space station.
 * @return void
 */
void sendPositionSingleLine(bool bISSPath) {
  char szTemp[15];    //largest string held should be the longitude
  int i;
  double insideTemp;    //inside air temp
  
  double airPressure;    //millibars
  float fTemp;    //temporary variable

  char statusIAT = 0;
  
  if (Config.getI2cBME280()) {
    if (Config.getStatusXmitPressure() || Config.getStatusXmitTemp()) {
      //we're supposed to transmit the air pressure and/or temp - go ahead and pre-fetch it
      airPressure = (double)Pressure.readFloatPressure();
      airPressure = airPressure / 100;    //convert back to simple airpressure in hPa
      insideTemp = (double)Pressure.readTempC();
    }
  }

  if (bISSPath) {
    //we're supposed to use the ISS path
    Aprs.packetHeader(Config.getDestination(), Config.getDestinationSSID(), Config.getCallsign(), Config.getCallsignSSID(), "ARISS ", '0', "      ", '0', true);
  } else {
    //we're supposed to use the normal path
    Aprs.packetHeader(Config.getDestination(), Config.getDestinationSSID(), Config.getCallsign(), Config.getCallsignSSID(), Config.getPath1(), Config.getPath1SSID(), Config.getPath2(), Config.getPath2SSID(), (GPSParser.Altitude() < Config.getDisablePathAboveAltitude()));
  }
  
  //      /155146h3842.00N/09655.55WO301/017/A=058239
  uint8_t hh = 0, mm = 0, ss = 0;
  GPSParser.getGPSTime(&hh, &mm, &ss);
  Aprs.packetAppend((char *)"/");

  sprintf(szTemp, "%02d", hh);
  Aprs.packetAppend(szTemp);
  sprintf(szTemp, "%02d", mm);
  Aprs.packetAppend(szTemp);
  sprintf(szTemp, "%02d", ss);
  Aprs.packetAppend(szTemp);

  Aprs.packetAppend((char *)"h");
  //Latitude
  GPSParser.getLatitude(szTemp);
  i=0;

  while (i<7 && szTemp[i]) {
    Aprs.packetAppend(szTemp[i]);
    i++;
  }
  Aprs.packetAppend(GPSParser.LatitudeHemi());
  Aprs.packetAppend(Config.getSymbolPage());

  //Longitude
  GPSParser.getLongitude(szTemp);
  i=0;
  while (i<8 && szTemp[i]) {
    Aprs.packetAppend(szTemp[i]);
    i++;
  }

  Aprs.packetAppend(GPSParser.LongitudeHemi());
  Aprs.packetAppend(Config.getSymbol());

  //Course
  fTemp = GPSParser.Course();

  sprintf(szTemp, "%03d", (int)fTemp);
  Aprs.packetAppend(szTemp);
  Aprs.packetAppend('/');

  //Speed in knots
  fTemp = GPSParser.Knots();
  sprintf(szTemp, "%03d", (int)fTemp);
  Aprs.packetAppend(szTemp);

  Aprs.packetAppend((char *)"/A=");
  //Altitude in Feet
  fTemp = GPSParser.AltitudeInFeet();
  Aprs.packetAppend((long)fTemp, true);

  if (Config.getStatusXmitGPSFix()) {
    //Fix quality and num sats

    if (GPSParser.FixQuality() >= 1 && GPSParser.FixQuality() <=3) {
      //we have a GPS, DGPS, or PPS fix
      Aprs.packetAppend((char *)" 3D");
    } else {
      Aprs.packetAppend((char *)" na");
    }
    sprintf(szTemp, "%d", GPSParser.NumSats());
    Aprs.packetAppend(szTemp);
  }

  if (Config.getStatusXmitBatteryVoltage()) {

    Aprs.packetAppend((char *)" V=");
    Aprs.packetAppend(Tracker.readBatteryVoltage(false));
  }

  if (Config.getI2cBME280() && Config.getStatusXmitTemp()) {
    Aprs.packetAppend((char *)" IAT=");
    Aprs.packetAppend((float)insideTemp);
  }

  if (Config.getI2cBME280() && Config.getStatusXmitPressure()) {
    Aprs.packetAppend((char *)" Press=");
    Aprs.packetAppend((float)airPressure);
  }

  if (Config.getStatusXmitSeconds()) {
    Aprs.packetAppend((char *)" S=");
    Aprs.packetAppend((long)(millis() / 1000), false);
  }

  if (Config.getStatusXmitBurstAltitude() && bHasBurst) {
    Aprs.packetAppend((char *)" Burst=");
    fTemp = fMaxAlt * METERS_TO_FEET;
    Aprs.packetAppend((long)fTemp, true);
  }
 
  Aprs.packetAppend(' ');
  Aprs.packetAppend(Config.getStatusMessage());
  Tracker.readBatteryVoltage(true);  //read the battery voltage before the transmission
  Aprs.packetSend();

  //Normally seeing about 280mV of drop during the transmission with a 0.5F supercap - Correction: seeing about 800mV with .5F as of 5/16/2025
  Tracker.readBatteryVoltage(true);  //read the battery voltage after the transmission
}


/**
 * @brief showVersion - Displays the version of the firmware and configuration
 * @return void
 */
void showVersion() {
  Serial.println(F("ptSolar Tracker"));
  Serial.print(F("Firmware Version: "));
  Serial.println((char *)FIRMWARE_VERSION);
  Serial.print(F("Config Version: "));
  Serial.println(CONFIG_VERSION);
  Serial.flush();
}
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

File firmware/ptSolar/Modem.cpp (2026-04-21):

/*
APRS Data Modem for Project: Traveler Flight Controllers
Copyright 2011-2026 - Zack Clobes (W0ZC), Custom Digital Services, LLC

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
You should have received a copy of the GNU General Public License along with this program.  If not, see <http://www.gnu.org/licenses/>.

Version History:
Version 2.0.5 - April 11, 2026 - Fix when passing signed longs out for altitude.
Version 2.0.4 - September 25, 2025 - Fixed potential overflow issues when printing longs. Adjusted timer overflow to account for cold-temperature operation.
Version 2.0.3 - August 25, 2025 - Forced the Tx line to the SA818 to be low prior to powering down, to fix bad start-up behavior.
Version 2.0.2 - July 20, 2025 - Synchronized the ptFlex and ptSolar code bases to be parameterized by the TRACKER_PTFLEX and TRACKER_PTSOLAR defines.
Version 2.0.1 - July 12, 2025 - Fixed bug that was corrupting the first packet.
Version 2.0.0 - March 9, 2025 - Major refactoring to make use of the DRA/SA818V transmitter module. Based on the prior TNC module from the ptFlex-series of trackers.

*/

#include "Modem.h"
#include "Arduino.h"
#include <SoftwareSerial.h>

/**
 * @brief Initializes the APRS object with the pins for the transmitter and serial port.
 * @param pinEnable The pin to enable the transmitter.
 * @param pinPTT The pin to key up the transmitter.
 * @param pinTxAudio The pin to send audio to the transmitter.
 * @param pinSerialTx The pin to transmit serial data to the 818V module.
 * @param pinSerialRx The pin to receive serial data from the 818V module.
 */
Modem::Modem(uint8_t pinEnable, uint8_t pinPTT, uint8_t pinTxAudio, uint8_t pinSerialTx, uint8_t pinSerialRx) {
  this->_pinEnable = pinEnable;
  this->_pinPTT = pinPTT;
  this->_pinTxAudio = pinTxAudio;
  this->_pinSerialTx = pinSerialTx;
  this->_pinSerialRx = pinSerialRx;

  pinMode(this->_pinEnable, OUTPUT);   //Always configure the enable pin as an output
  pinMode(this->_pinPTT, OUTPUT);     //Always configure PTT as an output
  pinMode(this->_pinTxAudio, INPUT);    //Configure as an input until we need it.

  //Disable the transmitter until we need it.
  digitalWrite(this->_pinPTT, LOW);    //Stop the transmit - 
  digitalWrite(this->_pinEnable, LOW);    //disable the transmitter


  this->_txDelay = 30;    //default to 30 if not otherwise defined.
  this->_lastTransmitMillis = 0;    //initialize the last transmit time to zero

  _iSZLen = -1;      //reset back to a clean buffer
  this->PTT(false);   //make sure the transmitter is unkeyed
}


/**
 * @brief  Keys up the 818V transmitter. Passes through the Tx/Rx frequency during the process.
 * @param  tx: A boolean indicating whether or not to key up the transmitter or unkey into receive mode.
 * @notes  The configuration of the module should be done each time the chip is taken out of PowerDown mode.
 */
void Modem::PTT(bool tx) {

  char response;
  long start;

  wdt_reset();    //reset the watchdog timer

  if (tx) {
    this->configTimers();   //always make sure the ISR and PWM timers are configured prior to transmitting

    //Configure the analog output for the audio
    pinMode(this->_pinTxAudio, OUTPUT);
    analogWrite(this->_pinTxAudio, 128);   //Set the audio output to 128. Subsequent calls in the ISR will write directly to the OCR2B register.

    //Turn on the transmitter
    digitalWrite(this->_pinSerialTx, LOW);    //set the serial port to low when powering up
    delay(10);
    digitalWrite(this->_pinEnable, HIGH);
    
    //Configure the serial port
    SoftwareSerial* XMIT = nullptr;
	  XMIT = new SoftwareSerial(this->_pinSerialRx, this->_pinSerialTx, false);
	  XMIT->begin(9600);
    delay(100);
    wdt_reset();    //reset the watchdog timer

    //Configure the transceiver
    if (this->_debugLevel > 0) {
      Serial.println("");
      Serial.print(F("Set Freq: "));
      Serial.println(this->_szTxFreq);
    }

    //Connect to the radio chip
    if (this->_debugLevel > 0) Serial.println(F(">AT+DMOCON"));
    XMIT->print(F("AT+DMOCONNECT\r\n"));
    
    //Get the response:
    if (this->_debugLevel == 2) Serial.print("<");    //Show an incoming carrot
    start = millis();
    do {
      if (XMIT->available()) {
        response = XMIT->read();
        if ((this->_debugLevel == 2) && response != '\r' && response != '\n') Serial.print(response);     //debug the output from the response
      }
    } while (response != '0' && (millis() - start) < MAX_WAIT_TIMEOUT);
    if (this->_debugLevel == 2) Serial.println("");
    delay(100);



    if (this->_debugLevel > 0) Serial.println(F(">AT+DMOSETGR"));
    XMIT->print(F("AT+DMOSETGROUP=0,"));
    XMIT->print(this->_szTxFreq);
    XMIT->print(",");
    XMIT->print(this->_szRxFreq);
    XMIT->print(F(",0000,4,0000\r\n"));   //No CTCSS Tx, Sql 4, No CTCSS Rx

    wdt_reset();    //reset the watchdog timer

    //Get the response:
    if (this->_debugLevel == 2) Serial.print("<");    //Show an incoming carrot
    start = millis();
    do {
      if (XMIT->available()) {
        response = XMIT->read();
        if ((this->_debugLevel == 2) && response != '\r' && response != '\n') Serial.print(response);     //debug the output from the response
      }
    } while (response != '0' && (millis() - start) < MAX_WAIT_TIMEOUT);  
    
    wdt_reset();    //reset the watchdog timer

    if (this->_debugLevel == 2) Serial.println("");
    if (this->_debugLevel > 0) Serial.println(">AT+SETFIL");
    XMIT->print(F("AT+SETFILTER=1,1,1\r\n"));   //Set the tx/rx filters to 1,1,1


    //Get the response:
    if (this->_debugLevel == 2) Serial.print("<");    //Show an incoming carrot
    start = millis();
    do {
      if (XMIT->available()) {
        response = XMIT->read();
        if ((this->_debugLevel == 2) && response != '\r' && response != '\n') Serial.print(response);     //debug the output from the response
      }
    } while (response != '0' && (millis() - start) < MAX_WAIT_TIMEOUT);

    wdt_reset();    //reset the watchdog timer

    if (this->_debugLevel == 2) Serial.println("");
    if (this->_debugLevel > 0) Serial.println("");
    delay(100);

    // Clean up
    XMIT->end();	//close the serial port to the GPS so it doens't draw excess current
    delete XMIT;
    XMIT = nullptr;
    digitalWrite(this->_pinSerialTx, LOW);    //set the serial port to low before going into sleep mode or else it can cause the transmitter to not engage next time
    

    //Push the PTT
    digitalWrite(this->_pinPTT, HIGH);   //There's a delay of about 37mS from PTT going high to when RF is emitted.
  } else {
    //End of transmission. stop the PTT and shut down the transmitter
    digitalWrite(this->_pinPTT, LOW);
    digitalWrite(this->_pinEnable, LOW);
    //delay(10);

    //Configure as an input until we need it. This will save power.
    pinMode(this->_pinSerialTx, INPUT);
    pinMode(this->_pinSerialRx, INPUT);
    pinMode(this->_pinTxAudio, INPUT);    
  }
}
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

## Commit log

2025-01-11 New 1.0.0 PCB version in Kicad format
    Designed version 1.0.0 of the PCB in Kicad. Firmware is stubbed in but not yet functional.
    [ptSolar-B_Cu.gbr, ptSolar-B_Mask.gbr, ptSolar-B_Paste.gbr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]
2025-01-26 Updated to PCB 1.1.0. Firmware mostly validated. Switched to FET-based level translators.
    [Bill of Materials.csv, breakout.kicad_sch, ptSolar-Breakout.kicad_pcb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]
2025-01-27 Added Breakout Board for powering and programming the ptSolar.
    [ptSolar-Breakout.kicad_pcb, ptSolar-Breakout.kicad_sch]
2025-01-28 Restructured the folder structure of the project. Minor updates to README.
    [Bill of Materials.csv, breakout.kicad_sch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]
2025-01-28 Updating Bill of Materials
    [Bill of Materials.csv, ptSolar-Breakout.kicad_sch]
2025-02-17 Minor updates to the BOMs and schematics. Updates to Firmware for further testing.
    [Bill of Materials.csv, ptSolar-Breakout.kicad_sch, ptSolar.kicad_sch]
2025-03-02 PCB v1.1.1 to include renumbered parts, and slight upgrades to silkscreening. Upgraded to Kicad v9.
    [Bill of Materials.csv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]
2025-03-02 Updated Breakboard to v1.1.1. Added BME280 on board. Improved silkscreening. Updated to Kicad v9.
    [ptSolar-Breakout-B_Cu.gbr, ptSolar-Breakout-B_Mask.gbr, ptSolar-Breakout-B_Paste.gbr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]
2025-03-05 Correcting typo in fuse settings.
    [ptSolar.ino]
2025-03-11 Major refactoring of code. Configs moved out into ptConfig, and board-specific functions moved into ptTracker. Still a work in progress.
2025-03-14 Increased PWM frequency to improve tone generation.
2025-03-15 Reboot functionality added. Now can enter Config mode at any time and not just at boot up.
    [ptSolar.ino, ptTracker.h]
2025-03-15 Rewrote classes to use Constructor instead of Init. Moved all pinMode code into classes, and switched certain OUTPUTs to INPUTs when not in use, such as the audio tone out. Done to save power.
2025-03-17 Tuned the modem for maximum decode rates. Increased ISR rate. Still sitting around 70% decode on packets.
    [Timer Value Comparisons for Baud and Tone Generation.xlsx]
2025-03-22 Fixed issue with audio waveform clipping. Improved documentation, and made the lookup table more efficient by eliminating redundant information.
    [Timer Value Comparisons for Baud and Tone Generation.xlsx]
2025-03-23 Fixed a typo, and unded the compressed audio waveform. It was causing the audio tones to drop in frequency. Likely just needs PROGMEM set on the array.
    [Timer Value Comparisons for Baud and Tone Generation.xlsx]
2025-03-24 Enabled audio filtering on the SA818V to improve decode rates.
2025-03-26 PCB v1.1.2 to fix audio clipping issues.
    [Bill of Materials.csv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]
2025-03-28 Updated 1.1.2 to include JLCPCB assembly with parts placement.
    [Bill of Materials.csv, ptSolar.kicad_pcb, ptSolar.kicad_sch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]
2025-04-05 Shortened debug strings to save 2.5% flash, and 11% of RAM.
    [Modem.cpp, ptConfig.cpp, ptSolar.ino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]
2025-04-05 Compressed sine lookup table by 50%.
    [Global APRS Frequency.xlsx, Timer Value Comparisons for Baud and Tone Generation.xlsx]
2025-04-05 Reworked the global frequency table to increase efficiency. Made corresponding XLSX sheet to update the table.
    [Global APRS Frequency.xlsx]
2025-04-06 Added courtesy tone support. Firmware v0.9.9 which is a potential release candidate for 1.0.0.
    [Timer Value Comparisons for Baud and Tone Generation.xlsx]
2025-04-07 Tweak to 1.1.2 to fix issue with transmitter being powered up during the boot process.
    The SA818V was pulling about 40mA during until the uC comes online.
    [Bill of Materials.csv, ptSolar.kicad_pcb, ptSolar.kicad_sch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]
2025-04-08 Rewired GPS Enable to switch power off to GPS module
    [Bill of Materials.csv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]
2025-04-12 Updated v1.1.2 with FET switch to shut down GPS. Generated Gerbers and sent off for manufacture.
    [Bill of Materials.csv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]
2025-05-02 Minor tweaks to power management. Firmware 9.9.10
2025-05-08 Fixed bug in displaying long ints. Flight tested, and promoting to version 1.0.0 of the ptSolar code base.
    [818v-tester.ino, Modem.cpp, ptSolar.ino]
2025-05-09 Leave GPS powered up during transmit. Clean up EnableGPS and DisableGPS so that it skips over that code if it's already En/Disabled.
    [ptSolar.ino]
2025-05-10 Adding debugging for potential memory leak. Cleaning up logic to improve GPS lock performance. Switched to 1.1V internal reference for batt measurements.
    [Modem.cpp, Modem.h, ptSolar.ino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]
2025-05-13 Added Watchdog timer, and traps to prevent from getting stuck in endless config mode. Fixed memory leak with GPS Software Serial, but appears to be another leak somewhere.
    [ptSolar.ino]
2025-05-13 Fixed typo, and updated to v1.0.1.
    [ptSolar.ino]
2025-05-14 Fixed GPS type not init'ing the GPS.
    [ptConfig.cpp, ptSolar.ino]
2025-05-15 Converted to dynamic SoftwareSerial objects. Getting crash when reading config.
    [Modem.cpp]
2025-05-16 v1.0.2. Implemented WDT throughout. Disabled GPS during xmit. Bug fix in Config mode.
    [Modem.cpp, Modem.h, ptConfig.cpp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]
2025-05-18 Version 1.1.0. Fixed bug in the geo-lookups, eliminated extra debug codes, enhanced the PT0100 config format, tweaked the delay logic when flying over xmit-prohibit areas.
    [Global APRS Frequency.xlsx]
2025-06-15 Added fuse setting script for initial programming
2025-06-22 Added cap, altered voltage divider values, eliminated extra solar panel pads.
    [ptSolar.kicad_pcb, ptSolar.kicad_sch]
2025-06-23 Updated SA818 pad, eliminated the excess 8-pin plug back to a 3-pin programming port. Started converting to Global Labels.
    [ptSolar.kicad_pcb, ptSolar.kicad_sch]
2025-06-24 Finalized version 1.2.0. Minor tweaks to the PCB, and added a hardware brown-out-detector chip to fix the boot up issue.
    [Bill of Materials.csv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]
2025-07-11 Updated firmware to reflect new 150k and 10k voltage sense divider circuit.
2025-07-12 Updated to firmware 1.5.0. This includes a few minor fixes, and an update to configuration version PT0101. Backwards support for alternate GPS and transmitters has been removed. Updated the resistor 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
    [Modem.cpp, ptConfig.cpp, ptSolar.ino]
2025-07-29 Adjusting voltage divider resistor precision.
    [Bill of Materials.csv, ptSolar.kicad_sch]
2025-08-21 Minor fix to capacitor C21. Regenerator Gerbers. Included the STL file for the Carrier. Rewrote set-fuses to allow repeat operations.
    [Bill of Materials.csv, ptSolar Carrier.FCStd, ptSolar Carrier.stl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]
2025-09-27 Fixes to the tester
    [818v-tester.ino]
2025-09-27 General clean up
    [ptSolar-B_Cu.gbr, ptSolar-B_Mask.gbr, ptSolar-B_Paste.gbr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]
2025-09-27 Adjusting gitignore
    [ptSolar-Breakout-job.gbrjob, ptSolar-job.gbrjob]
2026-05-18 Updated .stls for improved mounting
    [Angled Carrier.FCStd, Balloon Neck Hanger.FCStd, Balloon Neck Hanger.stl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]
2026-05-18 Added logic to handle Invalid GPS fix delays to other transmission modes
    [ptSolar.ino]
2026-05-31 Limiting GPS debug noise
    [ptSolar.ino]
2026-05-31 Fix for GPS Delay being out of order in config strings
    [ptConfig.cpp]

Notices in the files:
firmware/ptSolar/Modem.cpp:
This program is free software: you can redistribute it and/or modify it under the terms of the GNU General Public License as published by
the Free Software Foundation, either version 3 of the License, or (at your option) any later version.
